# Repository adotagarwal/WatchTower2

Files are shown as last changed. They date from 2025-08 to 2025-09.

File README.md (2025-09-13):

# The Watch Tower WWVB transmitter - V2


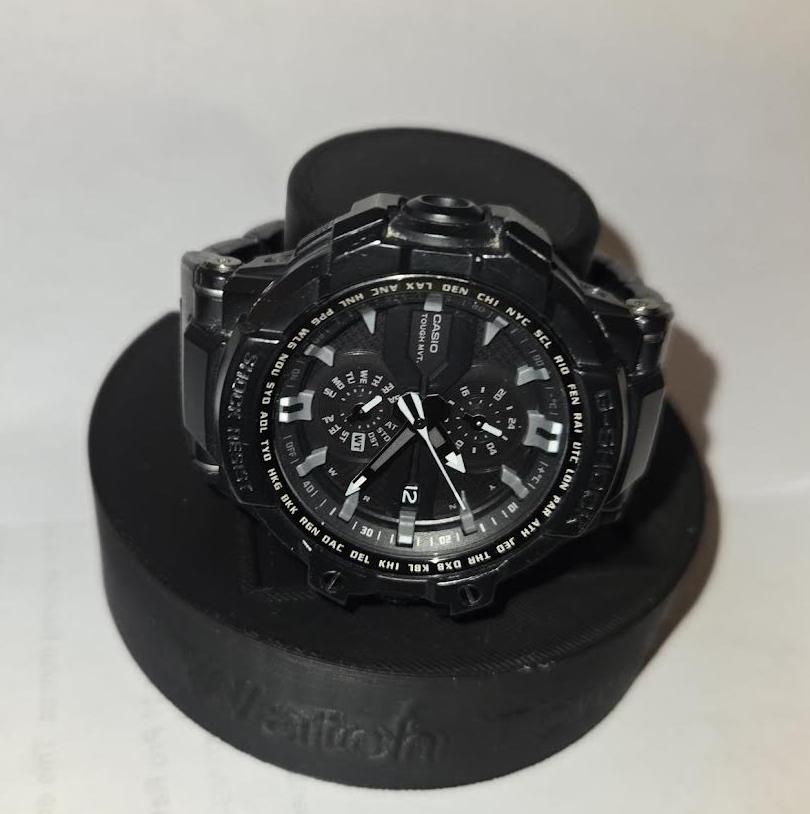
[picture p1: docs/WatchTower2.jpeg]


### This version has been updated to add a web gui for setting parameters (described in [424d3f8](https://github.com/adotagarwal/WatchTower2/commit/424d3f86f80151f93de71e6e73d6c25675c46d04)) and viewing log information, as well as supporting new protocols for time synchronization: WWVB, JJY (40&60), DCF77, MSF

This support was made possible by the work over at [time-signal](https://github.com/harlock974/time-signal) by Pierre Brial which I have adapted here.

## (NEW) UI
Settings tab preview:
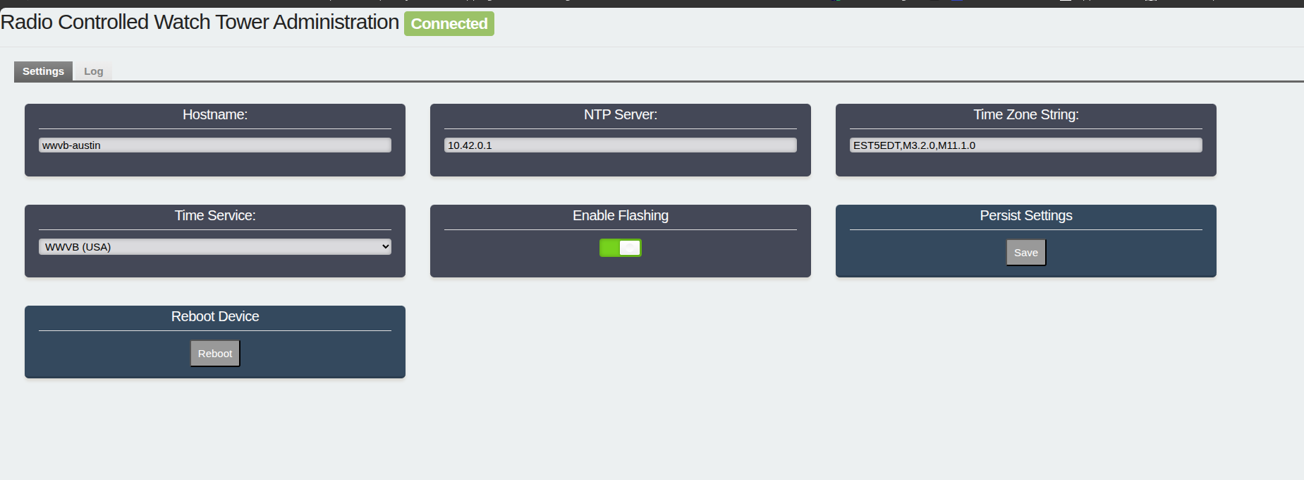
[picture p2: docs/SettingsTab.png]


Log tab preview:
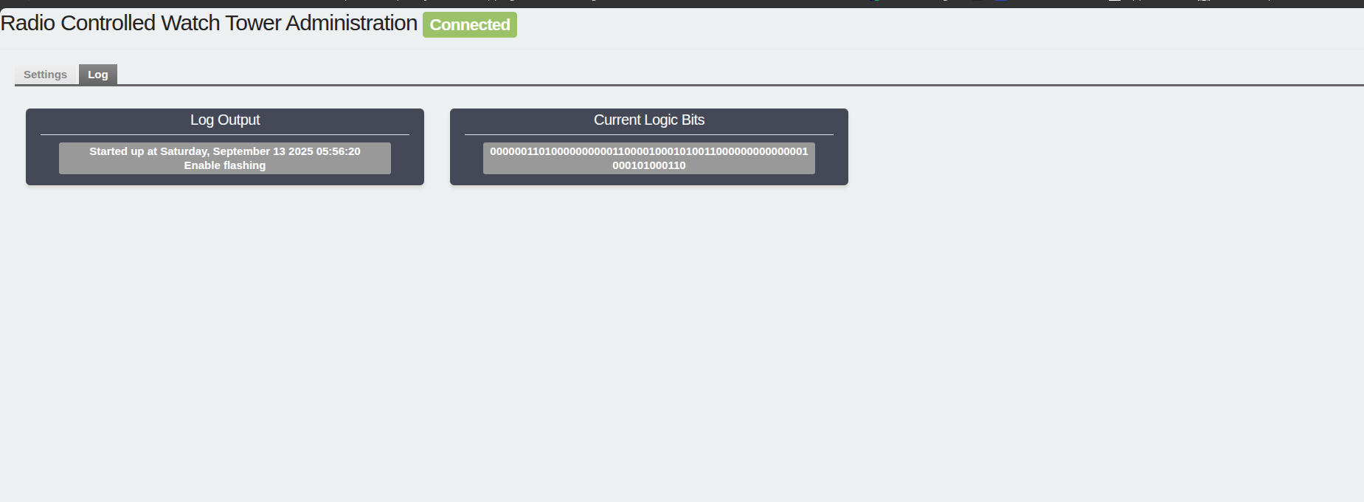
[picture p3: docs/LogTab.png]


Below is the original README

There are some beautiful radio-controlled watches available these days from Citizen, Seiko, Junghans, and even Casio. These timepieces don’t need fiddling every other month, which is great if you have more than one or two and can never remember what comes after “thirty days hath September…”

In the US, these watches work by receiving a 60-bit 1-Hz signal on a 60-kHz carrier wave broadcast from Fort Collins, Colorado called [WWVB](https://en.wikipedia.org/wiki/WWVB). The broadcast is quite strong and generally covers the entire continental US, but some areas of the country can have unreliable reception. I live in the SF Bay Area in an area with high RF noise and my reception can be spotty. My watches sync often enough that it’s not an issue 363 days out of the year, but sometimes they can miss DST shifts for a day or two. The east coast is known to be even more challenging. And people who live in other countries such as Australia have generally been out of luck.

Wouldn’t it be great if anyone anywhere in the world could set up a home transmitter to broadcast the time so their watches were always in sync?

WWVB has been around awhile and there have been various other projects ([1](https://www.instructables.com/WWVB-radio-time-signal-generator-for-ATTINY45-or-A/),[2](https://github.com/anishathalye/micro-wwvb)) that have demonstrated the feasibility of making your own WWVB transmitter. But these all had very limited range. I wanted to build something that could cover my whole watch stand and be based on a more familiar toolset for the typical hobbyist, namely USB-based 32-bit microcontroller development boards, WiFi, and Arduino. My goal was to make something approachable, reliable, and attractive enough it could sit with my watch collection.

## Is this legal?

The FCC requires a license to transmit, but has an [exemption](https://www.law.cornell.edu/cfr/text/47/15.209) for 60 kHz transmitters as long as the field strength is under 40 *μ*V/m at 300 meters. You will definitely not exceed this limit 💪🏼

## About WWVB

The classic WWVB transmits one bit of information per second (1Hz) and takes one minute (60 bits) to transmit a full time and date frame.

### An example

Here’s an example of one 60 second time encoding (graphic designed for "light mode"):

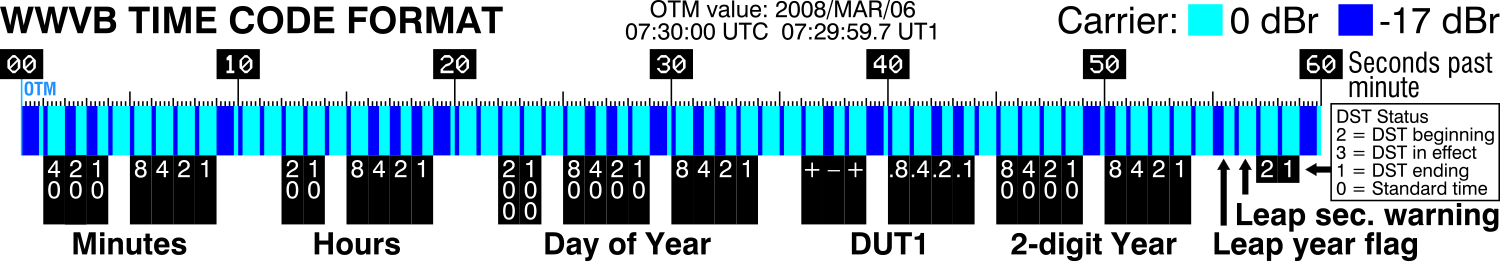
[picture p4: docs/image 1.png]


You can see that the minute of the time is encoded in the first 10 seconds of the window. The hour is in the next 10 seconds, the day is between seconds 22 and 33, etc.

If we wanted to indicate that the time was 30 minutes past the hour, for example, we would set bits 2 and 3 (20 and 10) to “high”. 

| **Bit** | **00** | **01** | **02** | **03** | **04** | **05** | **06** | **07** | **08** | **09** |
| --- | --- | --- | --- | --- | --- | --- | --- | --- | --- | --- |
| **Value** |  | 40 | 20 | 10 |  | 8 | 4 | 2 | 1 |  |
| *Example: 30* |  | *0* | *1* | *1* |  | *0* | *0* | *0* | *0* |  |

Similarly, the 7th hour of the day would be 0000111 for bits 12 thru 18.

### It’s a trit, not a bit.

How do we represent “high” and “low” for each 1s bit? You might think it would just be a high voltage for high and a low voltage for low, like you would use on a digital arduino pin, but that’s not how it’s done.

WWVB “bits” are actually not just 0 and 1. They’re actually "trits” because they can represent a 0, 1, or a “mark”, and this is one reason why we can’t just use a simple high/low to represent them. The mark is important to allow simple receivers to orient themselves within the signal window. Your watch knows that the last second in the window and the first in the next window are both “marks”, and so it knows to start a new window whenever it sees two marks in a row.

WWVB uses **Pulse Width Modulation** (PWM) to represent the three possible trit states. In a given 1 second bit, the width of the pulse determines whether the bit is a 0, 1, or mark.

- If power is reduced for one-fifth of a second (0.2 s), this is a data bit with value zero.
- If power is reduced for one-half of a second (0.5 s), this is a data bit with value one.
- If power is reduced for four-fifths of a second (0.8 s), this is a special non-data "mark", used for framing.

| **Low** | **Trit value** |
| --- | --- |
| 0.2s | 0 |
| 0.5s | 1 |
| 0.8s | mark |

Coming back to that original example but just focusing on the Minutes section, you can see the trits in the color encoding of the diagram. 

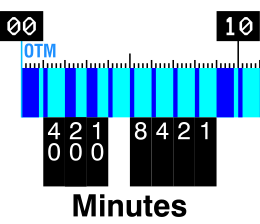
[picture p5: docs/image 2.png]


#07FEFF `Light blue` is high and #0001FC `Dark blue` is low. You can see second 00 is dark blue (low) for 0.8s, which means it’s a “mark”.  Second 01 is dark blue for 0.2s, so it’s a 0. Second 02 is dark blue for 0.5s so it’s a 1, and so on.

So now you know how to encode the time and date using WWVB!

### The carrier wave

There’s one more part of the signal that needs explanation. While we’re transmitting bits at a frequency of 1 bit per second (1 Hz), we’re actually doing it on top of a 60 kHz carrier wave by varying the amplitude of the carrier wave.

Like we said in the previous section, we represent a high/low/mark trit by the width of our pulse. High for 200ms is a zero, high for 500ms is a 1, high for 800ms is a mark. The way we’ll do that on our 60 kHz carrier wave is by using PWM again, but this time on the 60 kHz signal instead of on the 1 Hz signal. We’ll use a duty cycle of 50% to represent High, which means that half of our 60 kHz pulse is high and half is low. We’ll use a duty cycle of 0% to represent Low which effectively means the whole pulse is low.
 
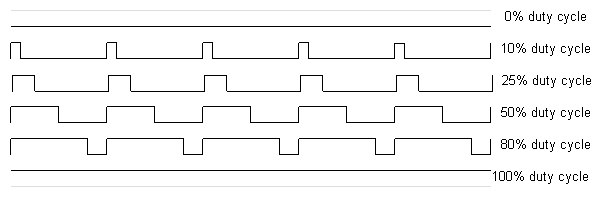
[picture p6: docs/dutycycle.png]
 

 So what you'll expect to see when you're transmitting a WWVB "mark" is a 1s pulse where half of the pulse is "high" using a 60 kHz signal at 50% duty, and the other half is "low" with a 0% duty (not to scale):

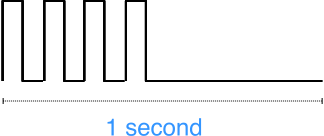
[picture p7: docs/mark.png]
mark
 

 Similarly, a 0 would be a 60 kHz 50% duty cycle for 0.2s, followed by a 0% duty cycle for 0.8s. And a 1 would be the reverse.

### The layers of WWVB

In summary, a WWVB date/time is encoded using a few different layers of encoding. At the top is what we think of as a date/time and at the bottom is the 60 kHz carrier wave.

|  |
| --- |
| A date/time is encoded as a… |
| 60-bit frame, using… |
| 1s PWM trits, on top of a… |
| 60 kHz 50% duty cycle carrier wave |
| 🐢🐢🐢 all the way down |

Now that you understand how it works, let’s build the transmitter!

## Components

- An ESP32-based development board such as the AdaFruit QT Py ESP32, AdaFruit Feather ESP32 v2, Arduino Nano ESP32, Seeed Xiao ESP32C3 or similar. I used the [QT Py ESP32](https://www.adafruit.com/product/5395).
- An H-bridge amplifier circuit. You can build your own, or I used the [Adafruit DRV8833 DC/Stepper Motor Driver Breakout Board](https://www.adafruit.com/product/3297). Boards using the TB6612 would probably also work, you just need something that can handle 5V or more, a few hundred milliamps and a switching frequency of 60khz or higher.
- One or two [60khz ferrite rod antennas](https://www.canaduino.ca/product/60khz-atomic-clock-receiver-v4-wwvb-msf-jjy60/). You can pull one from an existing quartz radio-controlled movement, or I bought mine from Canaduino. If you want better reliability at distance you may consider using a second antenna. Some users have had luck with a simple 20 inch length of straight copper wire, but I found the signal to be too weak to be reliable.
- Bread board and [jumper wires](https://www.amazon.com/dp/B08YRGVYPV).
- PCB Mount Screw Terminal Block connector to connect your antenna(s), something like [this](https://www.amazon.com/dp/B09F6TC7RP). Not strictly necessary but nice to have. Use a two pin terminal if you only plan to have one antenna, or a four pin if you want two antennas.

## Optional

None of the following is necessary, but some of it might be nice to have.

- **Oscilloscope**. It can be hard to know if your circuit is doing anything without an oscilloscope. There are some micro DSOs for around $100, and some android-based table DSOs for around $200, but I like the Rigol DHO800 series as an entry-level oscilloscope if your budget can stretch to around $400. A digital multimeter or an individual LED can also be helpful in a pinch.
- **10V power supply**. If you need more power you can use an external power supply. I found the signal to be strong enough without it and preferred the convenience of a single USB power supply. If you want to go up to 13V, switch to the [TB6612](https://www.adafruit.com/product/2448)
- **3D printer** if you would like to print the tower enclosure for your circuit.
- **Permaboard** or **Perma-proto**. After you’ve prototyped your circuit you’ll want to move it to something more permanent. [Perma-proto](https://www.adafruit.com/product/571) is convenient because it exactly matches your breadboard layout. Permaboard is more configurable but less convenient. Either one can be cut to size.
- **Soldering iron**. If you’re using permaboard, you’ll need a soldering iron. I love the [Pinecil v2](https://pine64.com/product/pinecil-smart-mini-portable-soldering-iron/), it’s USB-powered, auto-sleep, nearly instant-on, open-source and temperature controlled.
- **GPS module**. The nice thing about using module development boards like the Feather, Grove, Arduino, etc. is their support for additional modules. The [AdaFruit Ultimate GPS FeatherWing](https://www.adafruit.com/product/3133) pairs well with their Feather boards and includes an accurate RTC. If you go GPS, you don’t necessarily need a microcontroller with WiFi.
- **LCD display**. This can be a nice touch and can make it easier to tell if your tower is working or not. I like the [Adafruit ESP32 TFT Feather](https://www.adafruit.com/product/5483) or similar. I made an earlier prototype with a screen that displayed the current time, but didn’t like the way the screen lit up my bedroom at night. You can also connect many external displays using the simple I2C connector on many dev boards.

## Instructions

### Simulator

Before you get started, you might be interested to see a simplified version of the software in action on the Wokwi Arduino online simulator.

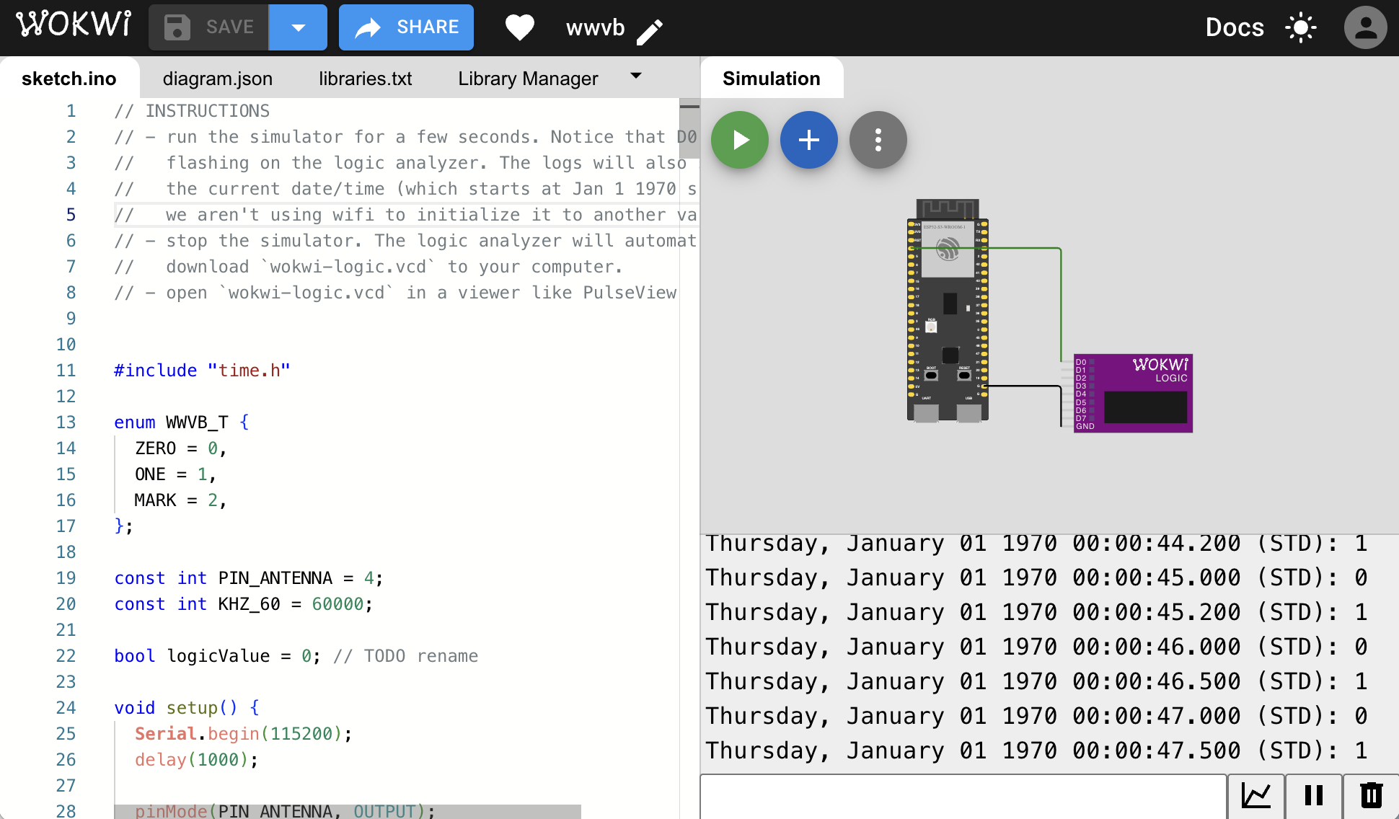
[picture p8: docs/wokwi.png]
The Watch Tower on Wokwi (https://wokwi.com/projects/431240334467357697)

https://wokwi.com/projects/431240334467357697

This simulator connects a virtual Arduino to a virtual logic analyser on PIN 4, and lets you download the output
of PIN 4 for offline viewing on your computer.

To use it:

- Run the simulator for a few seconds. Notice that D0 is
  flashing on the logic analyzer. The logs will also show
  the current date/time (which starts at Jan 1 1970 since
  we aren't using wifi to initialize it to another value)
- Stop the simulator. The logic analyzer will automatically
  download `wokwi-logic.vcd` to your computer.
- Open `wokwi-logic.vcd` in a viewer like [PulseView](https://sigrok.org/wiki/PulseView)

### Software

https://github.com/emmby/WatchTower

Upload the Arduino sketch to your Arduino using the Arduino IDE.

The LED will light up yellow/orange while connecting to WiFi. If you haven’t yet set your SSID, connect your phone to SSID: WWVB and follow the instructions to enter your wifi password.

Once the network is connected and the time has sync’d, the light will turn green briefly and then turn off.

**Setup()**

The Arduino setup() method does a few things.

Initialize the components we’ll be using, particularly the serial port, LEDs, WiFi, output pins, timezone, and network time sync (NTP). The network time sync will happen automatically in the background every hour. This is important because the realtime clock (RTC) on most microcontrollers are notoriously subject to drift and are rarely accurate for more than a few hours.

Start the 60 kHz carrier wave at a 50% duty cycle.

**Loop()**

Arduino then moves to the loop(), which continuously performs the following operations:

- Get the current time in UTC
- Convert it to your local timezone to determine DST
- Compute whether the 60 kHz carrier wave should be set to 50% (logical high) or 0% (logical low) for that specific moment in time. Time is always UTC, except for the DST bit which is relative to your local timezone.
- Set the PIN_ANTENNA to high or low based on that value.
- [Optional] you can flash the led for high/low PWM. This is nice for making sure things are working, but it’s grounds for divorce in the bedroom.

Do some other nice-to-haves like logging, setting LEDs and/or rebooting when there are issues.

### Verify the microcontroller alone

If you installed and ran your software and you set up the wifi connection, your board should now be outputting a signal on your output pin.

If you have an LED, you can connect the long end (anode) to your output pin and the other end to ground. If everything is working it should flash on/off about once a second.

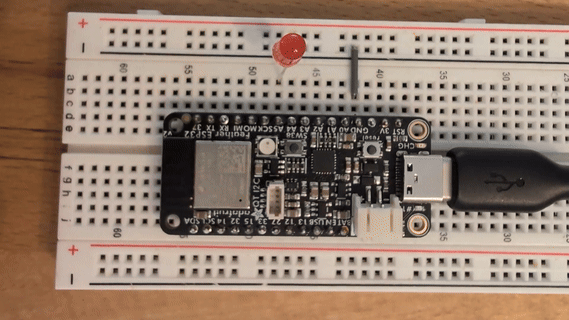
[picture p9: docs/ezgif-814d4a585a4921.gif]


If you have a digital oscilloscope, you should be able to see a 3V square wave with a periodicity of 16us (1 / 60,000) something like the following:

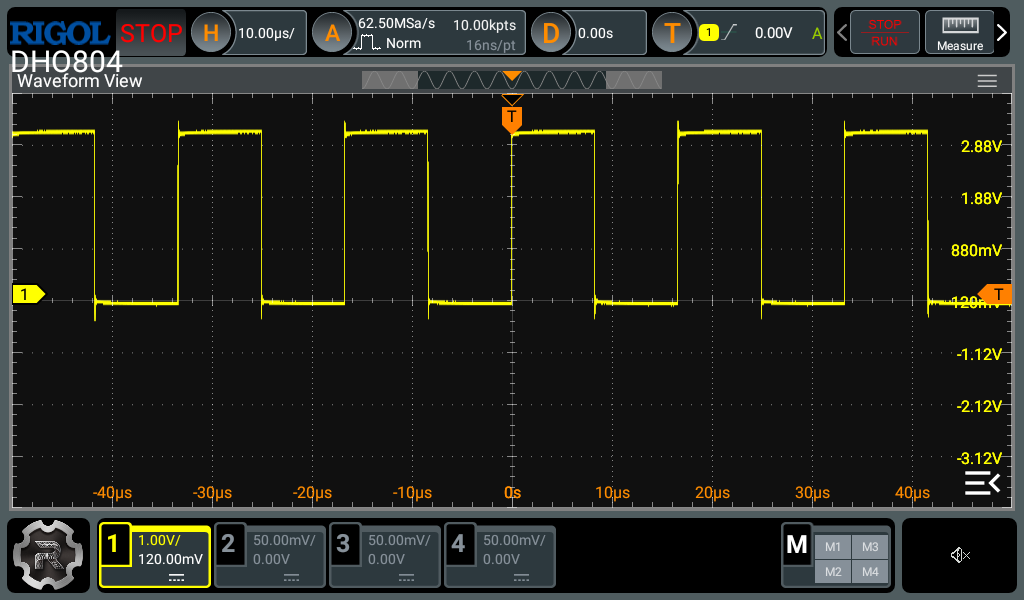
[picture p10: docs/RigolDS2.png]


That’s the 50% duty cycle PWM carrier wave initialized during setup().

If you zoom out to say 1 second per grid square resolution, you’ll be able to see the WWVB signal clearly:

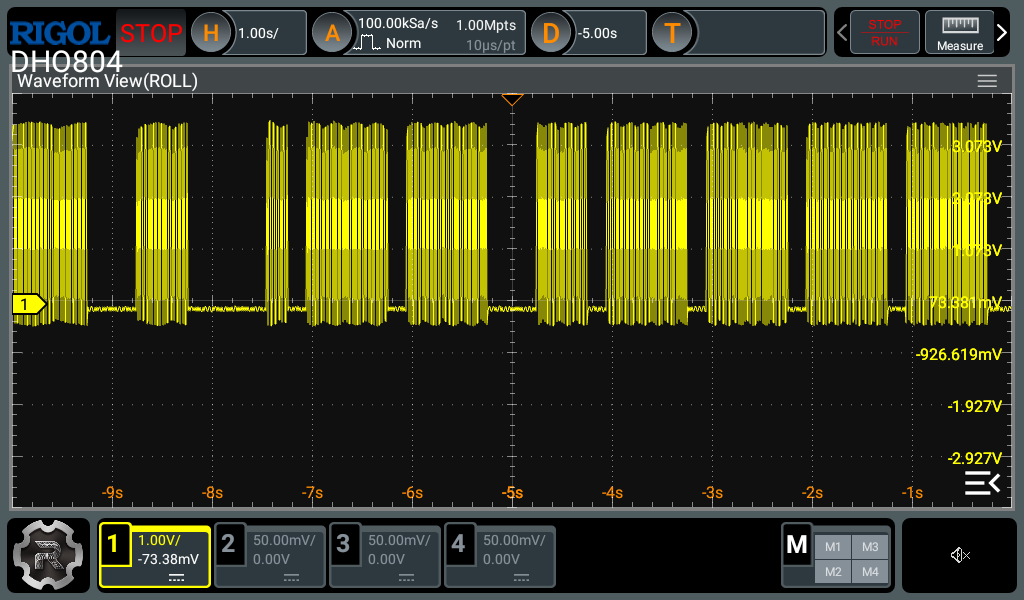
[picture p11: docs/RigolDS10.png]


In the 10 seconds shown here, I see a 1, mark, 0, 1, 1, mark, 1, 1, 1, and 1.

Now if you modify the software to hardcode the date to Mar 6, 2008 7:30:00 am and zoom out to see a full 60 seconds, your signal should exactly match the signal in the example we started with:

```c
  buf_now_utc.tm_year = buf_now_local.tm_year = 108; // 2008 = 1900 + 108
  buf_now_utc.tm_yday = buf_now_local.tm_yday = 65;
  buf_now_utc.tm_mon = buf_now_local.tm_mon = 2;
  buf_now_utc.tm_mday = buf_now_local.tm_mday = 6;
  buf_now_utc.tm_hour = buf_now_local.tm_hour = 7;
  buf_now_utc.tm_min = buf_now_local.tm_min = 30;
```

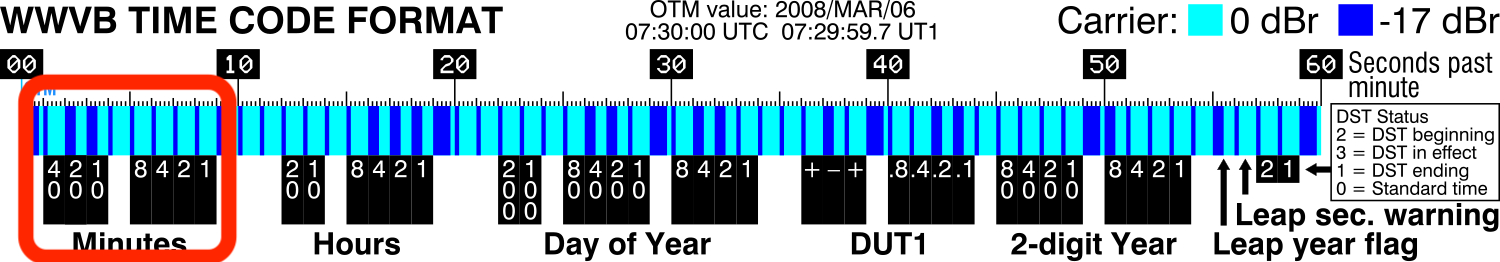
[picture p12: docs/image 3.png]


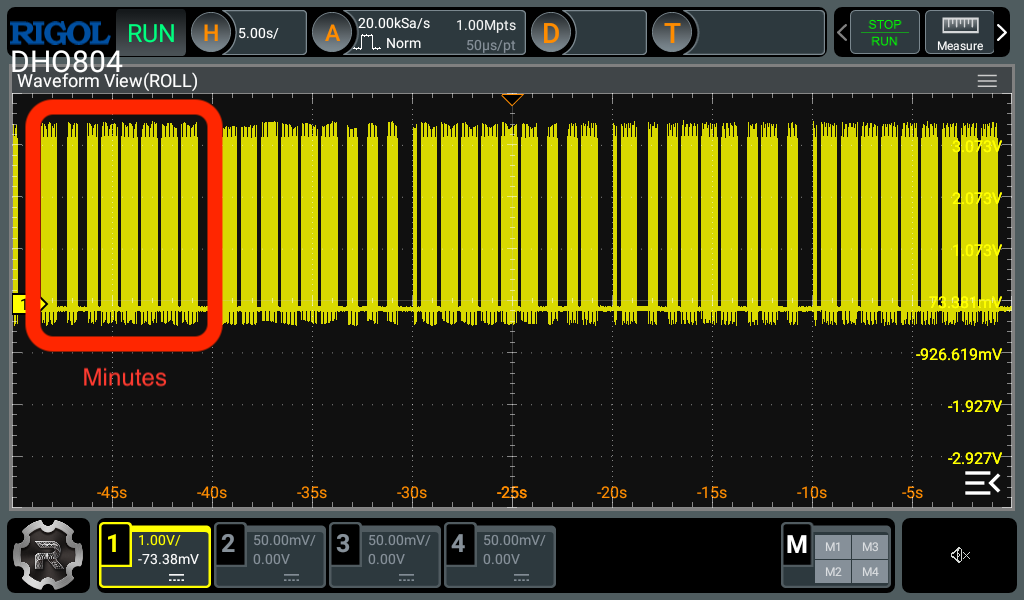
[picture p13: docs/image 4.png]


Looks great! Everything is working as expected.

### Electronics assembly

Now that you’ve verified the microcontroller is working, it’s time to put all the components together.

The electronics consist of three basic components: the microcontroller board, the amplifier breakout board, and the antenna(s).

The connections are quite simple, you can do them on a breadboard or a proto board. I recommend starting with a breadboard, which will look identical to this perma-proto board but without the solder:

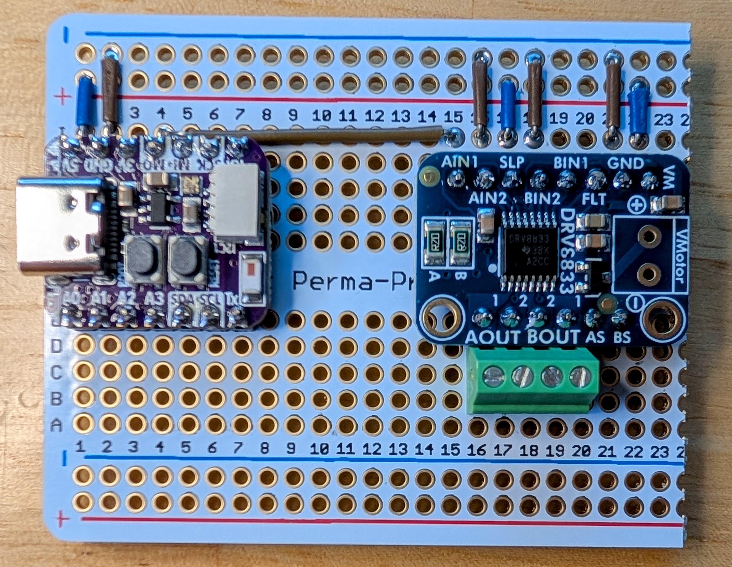
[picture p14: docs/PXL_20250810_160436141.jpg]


**Microcontroller board** (Adafruit ESP32 QT Py in this photo)

- Connect the 5V pin to the power plane (photo: J1).
- Connect the ground pin to the ground plane (photo: J2).
- Connect your signal pin [M0] to the input pin of your amplifier [AIN1] (photo: J4>J15).

**DRV8833 Amplifier breakout**

I decided to leave a gap between my microcontroller board and my amplifier board. This will support an optional second antenna mounted vertically, and it also makes it easier to access the STEMMA QT I2c connector on the QT Py.

- Connect the second input pin [AIN2] of your amplifier to ground (photo: J16).
- The Adafruit DRV8833 motor driver board has a sleep pin that needs to be pulled high to enable the breakout, so connect that to power 5v or 3v power, whatever is convenient. We used 5V here. (photo: J17)
- Connect ground to the ground plane. (photo: J21)
- [Optional] Connect the “motor” voltage [VM] to your 5V plane (photo: J22). This is needed if you are powering your amplifier via USB like I have here, but it should not be done if you are planning to use an external power supply on VMotor.
The antenna and amplifier circuit can contribute some noise to your 5V line. If you’re worried about it you might use an external power supply instead, but I found for these settings that the noise was negligible (although see Alternatives Considered for some lessons learned).
- Optional: connect BIN2 to ground (photo: J18). This is only needed if you want to use a second antenna.
- Optional: connect BIN1 to AIN1 (**not in photo**: I15>I19). For a second antenna.

**Antenna(s)**

- You can plug your antennas directly into your breadboard, or use a 0.1" Pitch PCB Mount Screw Terminal Block Connector connected to [AOUT1], [AOUT2], [BOUT2], and [BOUT1] (photo: C16, C17, C18, C19). If you are only using one antenna, you only need [AOUT1] and [AOUT2].

  The orientation of the antenna has a profound effect on the strength of the signal. I recommend using a second antenna at a 90 degree orientation to the first. You won't get a more powerful signal, but by having a second signal at a 90 degree orientiation you significanly increase the chance that your watches will be able to pick up a signal (see the section on antenna orientation below). The amplifier can easily handle two antennas.

  With one antenna, I was getting around 12 inches of range with the way my watches were oriented. With the second antenna, that jumped up to more than 6 feet!

  The STL tower has a hole in the center to allow space for a 60mm ferrite rod antenna mounted vertically in the gap between the microcontroller and amplifier PCBs.

### Signal Verification

You should be able to do the same LED trick as last time, only this time with the long anode on AOUT1 and the short cathode on AOUT2.

Or with your oscilloscope, you can look at the output of your microcontroller and compare it to the output of your amplifier:

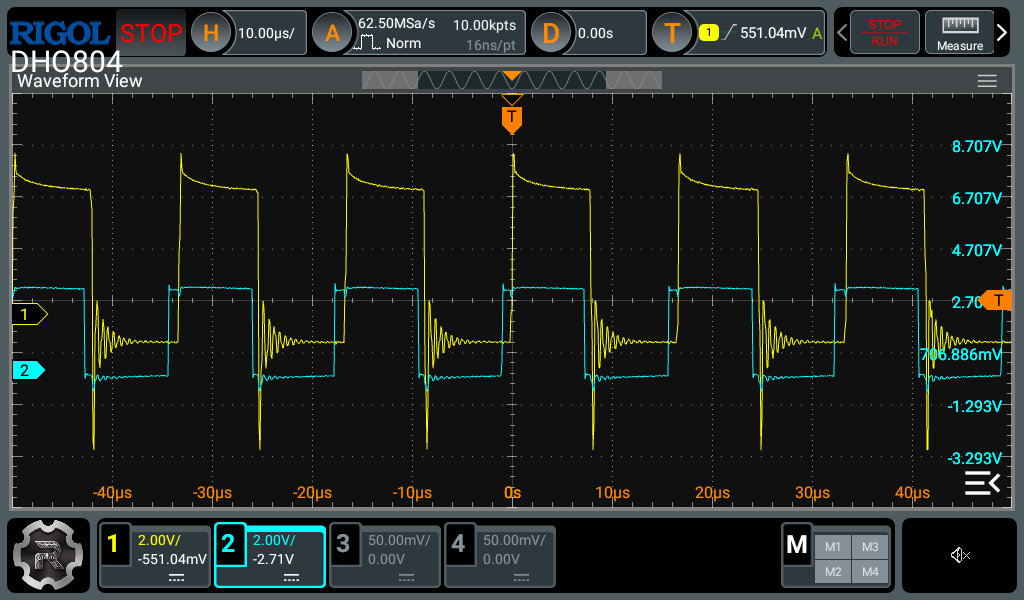
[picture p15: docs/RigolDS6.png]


Here the 3V signal on the microcontroller is blue, and you can see that the amplifier is outputting a similar wave but at 5V. If your wave doesn’t look quite like this, check that your antenna is plugged in. The antenna has an impedance that will cause the ringing that you see in the waveform, that’s expected and okay.

The final test is to verify it works with a real watch!



### Assembling the enclosure

The enclosure is designed for a 51mm x 63mm perma-proto, which is the size of a half size perma-proto with the excess trimmed. You can trim a proto board by scoring along a straightedge with a utility knife and then bending the board at the score, either by pressing it down on a hard surface at an angle or using a vise grip. Or feel free to modify the Autodesk Fusion file to the size of your own board.

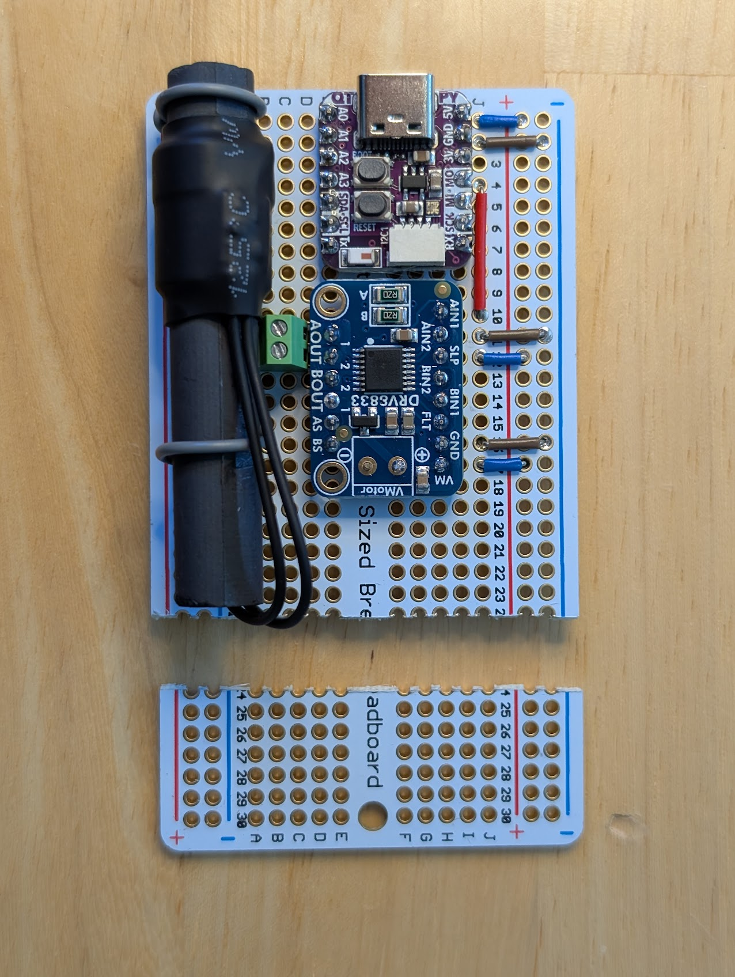
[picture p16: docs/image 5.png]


Here I also made a quick and dirty “mount” for the antenna by twisting a couple of loops of wire and soldering them to the perma proto. Hot glue also works great.

Print the enclosure using a 3D printer. I used standard PLA, standard 0.4mm nozzle, and pretty much default slicer settings with no supports.

* STL: [The Watch Tower.stl](enclosure/The%20Watch%20Tower%20v18.stl)
* Autodesk Fusion: [The Watch Tower.f3d](enclosure/The%20Watch%20Tower%20v18.f3d)

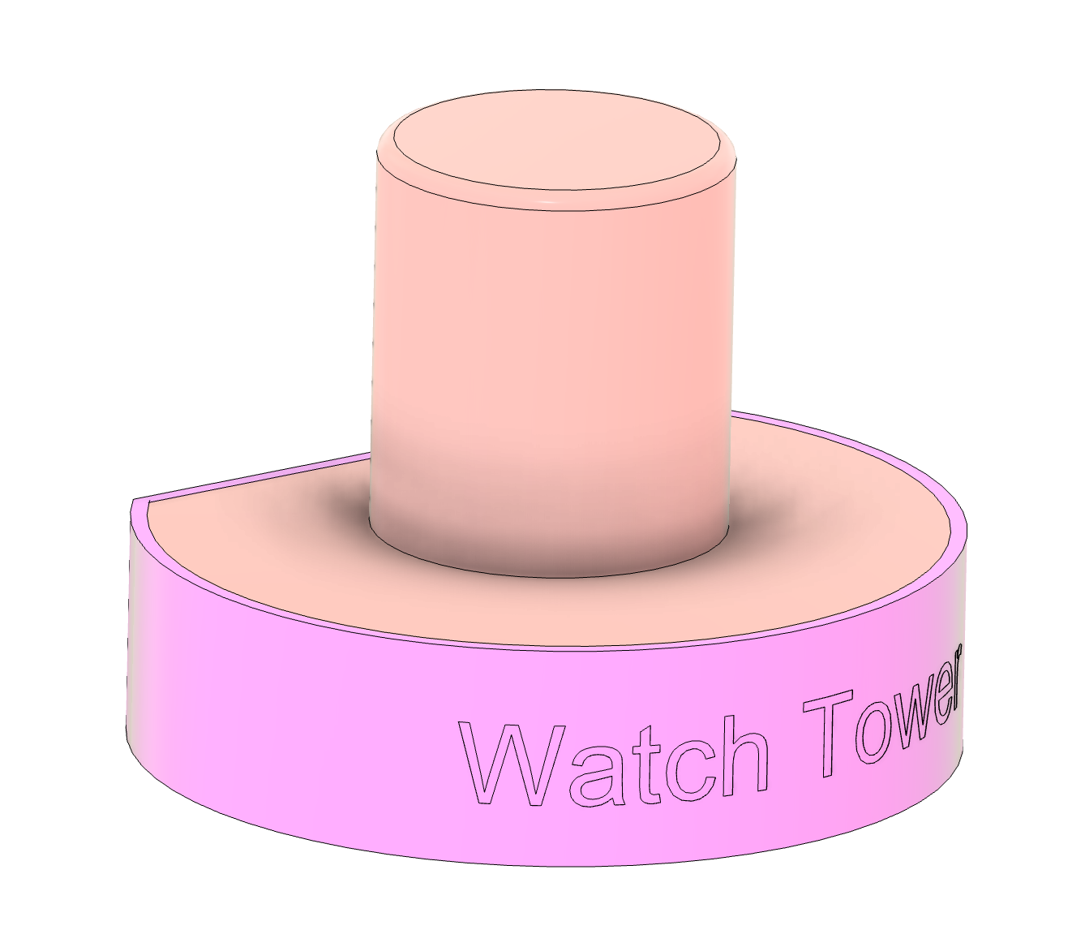
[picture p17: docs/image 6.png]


Insert the circuit board into the base. Orient the second antenna between the two PCBs and fit it into the hole in the tower. Then press the lid for a snap fit.

## Enjoy!

Plug into USB and you’re done! Your watches should now sync automatically every night.

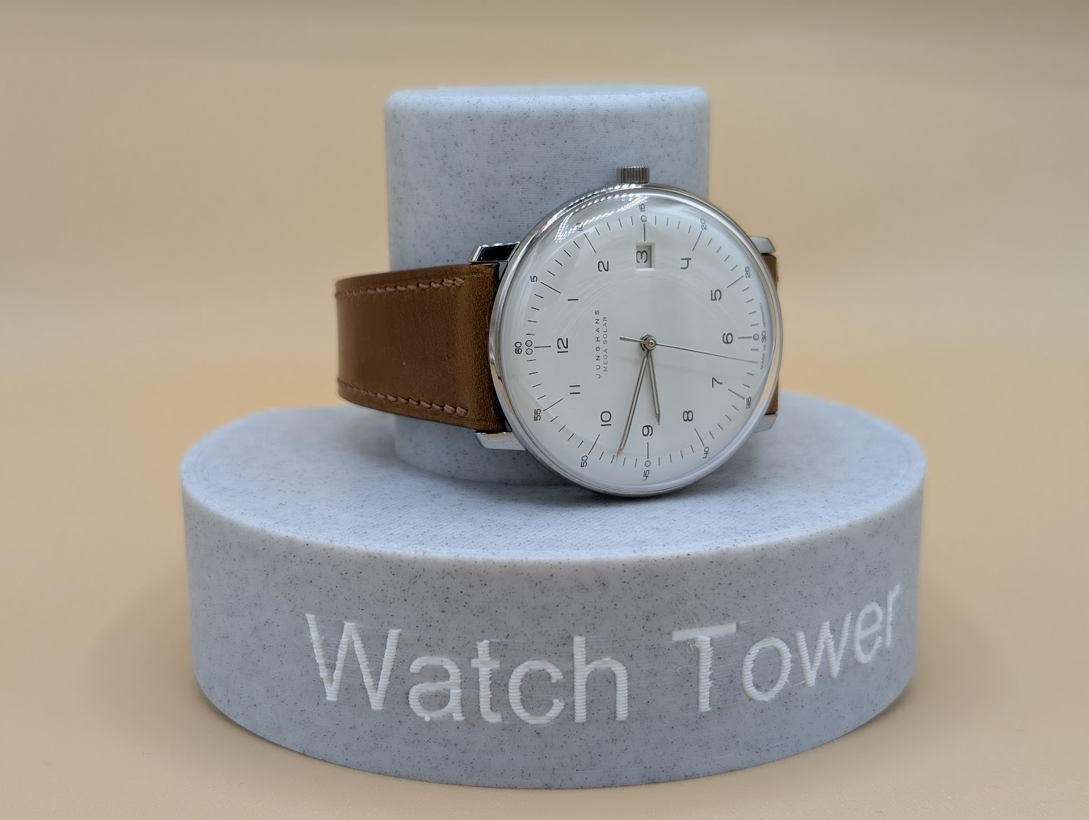
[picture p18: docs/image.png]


## Signal strength

### How does distance affect signal strength?

You probably expect the signal to decrease as you get further away from the tower, but you might be surprised by how quickly the signal disappears.

The "inverse square law" tells us that RF signal strength decreases with the square of the distance. We can measure our signal strength using our oscilloscope, another antenna, and a ruler.

signal strength at 1 inch setup

At one inch, our signal strength looks pretty solid! You can see that our 5V antenna square wave (yellow) is inducing a 16V sinusoidal wave in our receiving antenna. It's a little counter-intuitive that the receiving amplitude would be larger than the sending amplitude, but RF physics is beyond the scope of this README. Which is another way of saying 🤷.

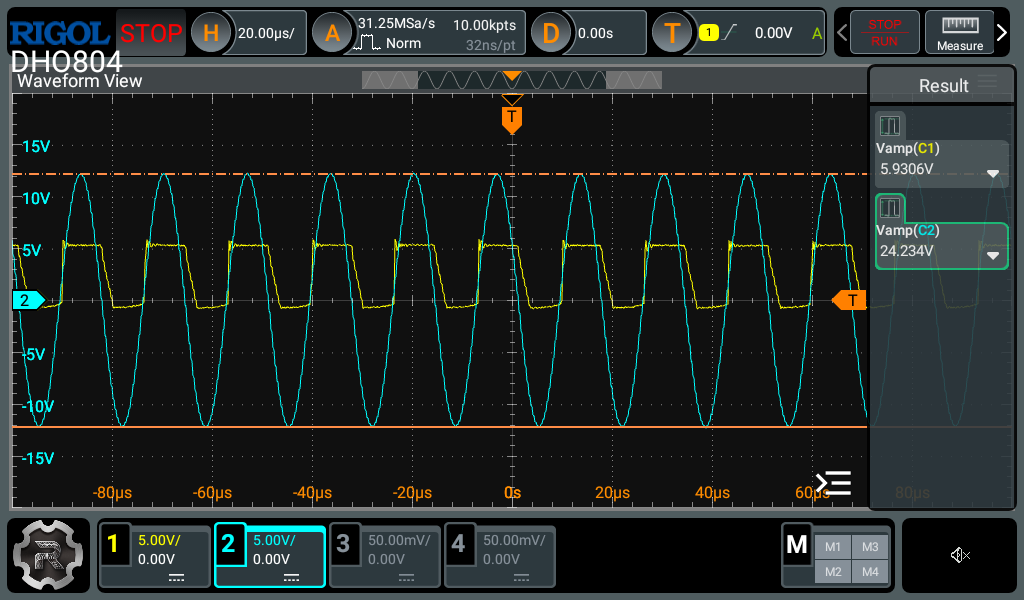
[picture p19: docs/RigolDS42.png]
signal strength at 1 inch


Here are my readings as I move the receiver antenna further out. As expected, the amplitude decreases by roughly 4X as the distance doubles. 

| Distance | Amplitude |
|----|---|
| 1" | 24.2V |
| 2" | 6.7V |
| 4" | 1.2V |
| 8" | 301mV |
| 16" | 93mV |
| 32" | 28mV |

When you zoom out, the one second pulses are still clearly distinguishable to the human eye, but it gets harder and harder as you get further away.

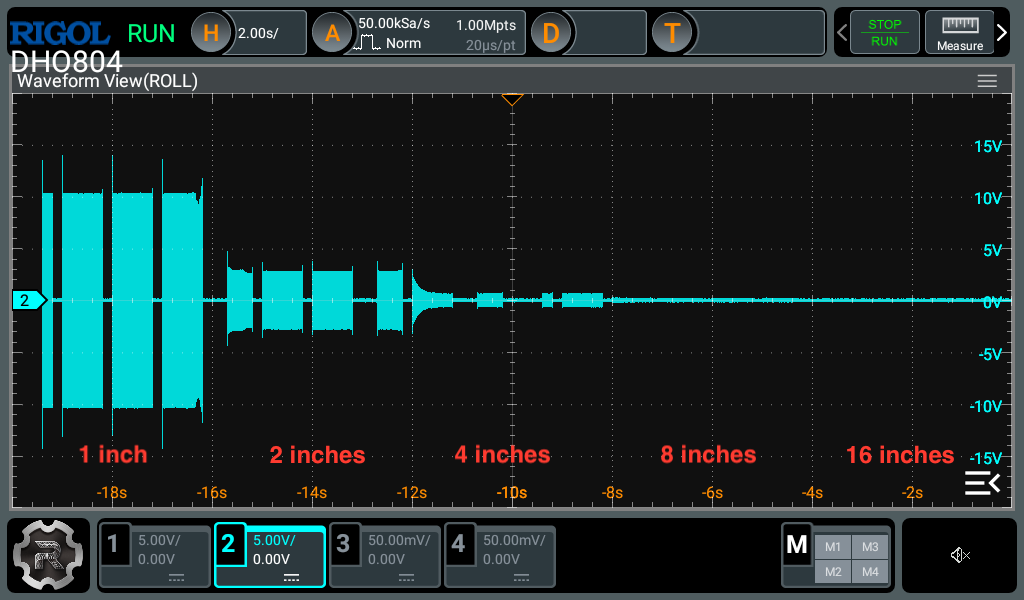
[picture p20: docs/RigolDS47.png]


This is all fine and good, but seeing a wave on an oscilloscope doesn't necessarily mean the watch can pick it up. We'll get into that shortly.

### How does orientation affect signal strength?

Quite a lot!

Turning the receiver antenna 90 degrees drops the signal by 75%!

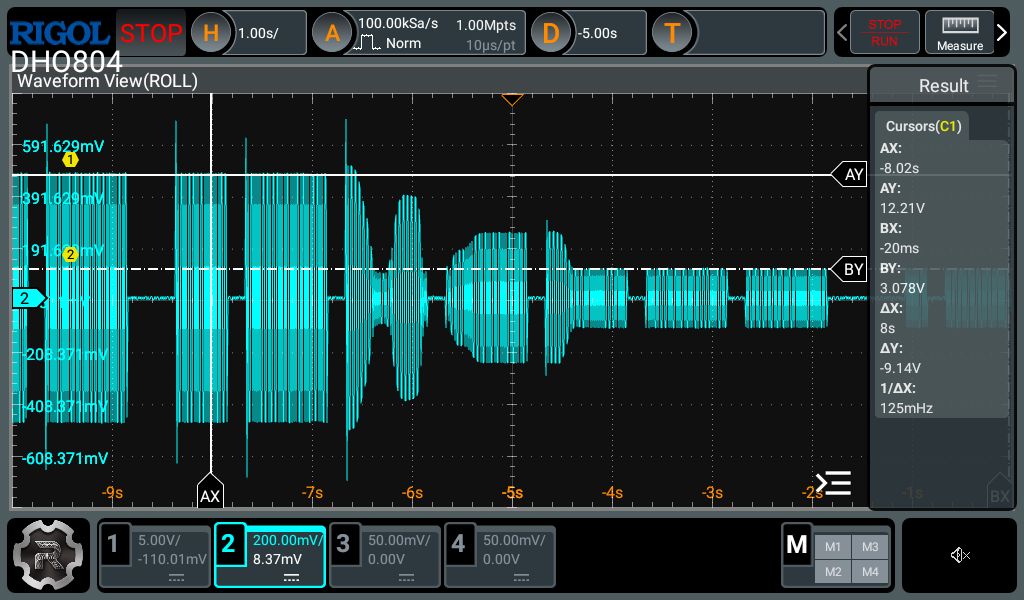
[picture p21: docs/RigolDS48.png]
rotation


Most watches receive their strongest signal through the watch face. For the best reception you should point your watch toward the tower (or toward Colorado). This may make more of a difference than a few inches of distance.

This doesn't matter for watches on the stand where the signal is strong, but it can make a difference for watches that are further away.

This is why I recommend two antennas at right angles from each other.

### Does the enclosure affect signal strength?

Plastic enclosures have a negligible effect on signal strength. The Watch Tower enclosure printed using generic PLA has maybe 5% or less of an impact on signal strength. Again, a few degrees of orientation will have a larger effect than an enclosure.

|||
|-|-|
|No enclosure | 1.02V |
|Base | 952mV |
|Fully enclosed | 987mV |

### How far away can my watch pick up the signal?

Watches vary in terms of their antenna design, their enclosures, antenna orientation, signal-to-noise filtering, etc.

I tested with a Junghans Max Bill Mega Solar 59/2021.02 (Seiko movement) and a Casio Lineage LIW-M700D (Casio movement). In practice, the orientation of your watch will probably have orders of magnitude more influence on your reception than the model of your watch.

Using the SINGLE antenna, I made five attempts with each watch at a distance of 9" with the antenna and the watch both flat on the surface. To minimize interference from Fort Collins, I placed everything inside a poor man's faraday cage (a stainless steel stock pot with a tight lid, which Gemini tells me is reasonably effective at blocking 60 kHz signals). For each attempt, I gave the watch 5 minutes to try to set the time before I lifted the lid. 

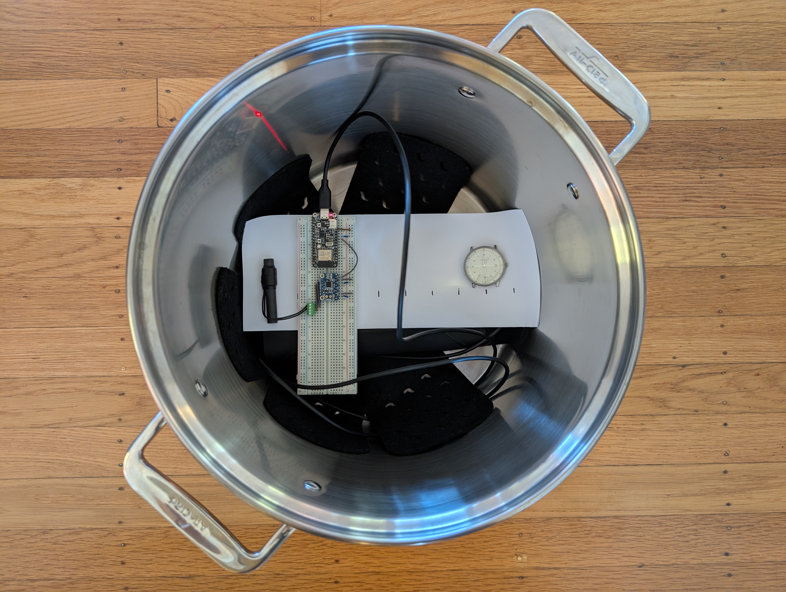
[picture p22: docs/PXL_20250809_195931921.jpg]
clock in a pot


| Model ||||||
|---|-----|-|-|-|-|
| Casio | Yes | No | Yes | Yes | Yes |
| Junghans| Yes | Yes | Yes | Yes | Yes |

Outcome: ~90% success at 9" (single antenna)

In practice, I've found that watches on the Watch Tower will reliably sync every time, and most watches on my nearby watch stand will also sync most of the time using a single antenna. Adding the second antenna increases reliability to basically 100%.

## Alternatives considered

- I wanted to avoid using a separate amplifier breakout board so I tried the Adafruit RP2040 scorpio. It can do 60khz PWM at 5V natively, but it was only able to drive 12mA per channel which wasn’t enough to saturate my ferrite antenna so the square wave collapsed.
- I looked at the **Adafruit 8-Channel PWM or Servo FeatherWing** because I wanted to take advantage of module stacking, but it can only do 10mA per channel and 1.6khz.
- I looked at Trinket and Itsybitsy ATmega based boards, but they can’t drive much current and they’re not modular with anything and they have no wifi so there’s little advantage over the QT Py.
- I considered driving the DRV8833 with an external power supply. This would have given me higher voltage and likely a stronger signal. But I wanted the convenience of a single usb power supply, and the signal strength was sufficient for my needs.
- ⚠️ **WARNING**: I tried the linking both the A and B H-bridges of the  DRV8833 in parallel, and I also upped the duty cycle to 80%. Totally blew out my microcontroller, presumably with a flyback voltage due to the high inductance antenna. I’m not sure if it was the parallel or the 80% or the combination of the two, it would be worth experimenting further but I haven’t yet.

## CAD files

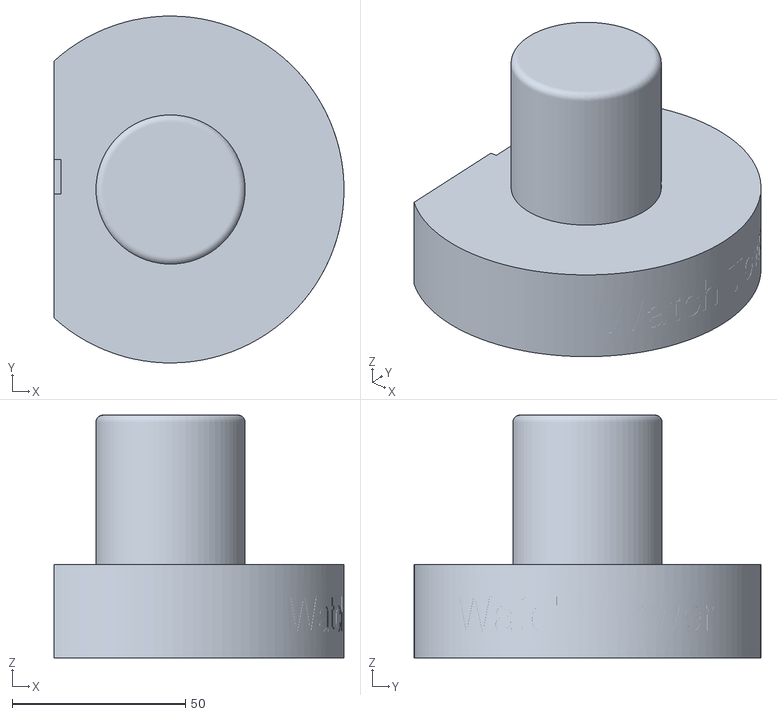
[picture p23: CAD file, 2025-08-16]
enclosure/original/The Watch Tower v18.stl
83.6 x 100.0 x 70.0

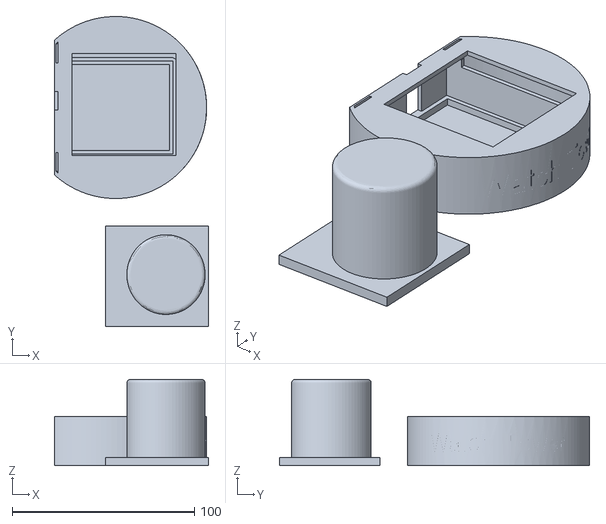
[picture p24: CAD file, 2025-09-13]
enclosure/WWVB Radio Watch Tower.stl
84.6 x 170.3 x 47.4

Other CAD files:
enclosure/original/The Watch Tower v18.f3d

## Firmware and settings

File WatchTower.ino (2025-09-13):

// INSTRUCTIONS
// - set the PIN_ANTENNA to desired output pin
// - download and run the code on your device
// - connect your phone to "WWVB" to set the wifi config for the device

// Designed for the following, but should be easily
// transferable to other components:
// - ESP32: https://www.adafruit.com/product/5395
// - DRV8833 breakout: https://www.adafruit.com/product/3297

#include <WiFiManager.h>
#include <Preferences.h>
#include <ESPUI.h>
#include "time.h"
#include "esp_sntp.h"
#include "time-services.h"
#include "wwvb-impl.h"

// Set these values to the pin numbers corresponding to those your antenna and onboard led are connected
const int PIN_ANTENNA = 23;
const int PIN_LED = 2;

//STATE VARIABLES
WiFiManager wifiManager;
Preferences thePreferences;
bool logicValue = 0; // TODO rename
uint64_t logicBits = 0;
struct timeval lastSync;
uint16_t liveLogHandle;
uint16_t liveLogicBitsHandle;
String logBuffer = "";

// PREFERENCE VARIABLES
bool enableFlashing = false;
enum time_service theService = WWVB;
String theNtpServer;
String theTimezone;
String theHostname;

// TIMEZONES: https://gist.github.com/alwynallan/24d96091655391107939

// A tricky way to force arduino to reboot
// by accessing a protected memory address
void(* forceReboot) (void) = 0;

// A callback that tracks when we last sync'ed the
// time with the ntp server
void time_sync_notification_cb(struct timeval *tv) {
    lastSync = *tv;
}

// A callback that is called when the device
// starts up an access point for wifi configuration.
// This is called when the device cannot connect to wifi.
void accesspointCallback(WiFiManager*) {
    Serial.println("Connect to WWVB with another device to set wifi configuration.");
}

void setup() {
  Serial.begin(115200);
  delay(1000);
  Serial.println("Starting...");
  
  pinMode(PIN_ANTENNA, OUTPUT);
  pinMode(PIN_LED, OUTPUT);

  // hack for this on esp32 qt py?
  // E (14621) rmt: rmt_new_tx_channel(269): not able to power down in light sleep
  digitalWrite(PIN_ANTENNA, 0);
  //digitalWrite(PIN_LED, 0);

  readPreferences();

  WiFi.setScanMethod(WIFI_ALL_CHANNEL_SCAN);

  Serial.println("Connecting to Wi-Fi...");

  // Connect to WiFi using // https://github.com/tzapu/WiFiManager 
  // If no wifi, start up an SSID called "WWVB" so
  // the user can configure wifi using their phone.
  wifiManager.setAPCallback(accesspointCallback);
  wifiManager.autoConnect(theHostname.c_str());

  Serial.println("Syncing NTP time...");

  // Connect to network time server
  // By default, it will resync every hour
  sntp_set_time_sync_notification_cb(time_sync_notification_cb);
  configTime(0, 0, theNtpServer.c_str());
  struct tm timeinfo;
  if(!getLocalTime(&timeinfo)){
    Serial.println("Failed to obtain time");
    flashFailure();
    delay(3000);
    forceReboot();
  }
  Serial.println("Got the time from NTP");
  flashSuccess();

  // Now set the timezone.
  // We broadcast in UTC, but we need the timezone for the is_dst bit
  updateTimezone();

  // Start the 60khz carrier signal using 8-bit (0-255) resolution
  int myFrequency = getFrequencyForService(theService);

  ledcAttach(PIN_ANTENNA, myFrequency, 8);
  
  createUi();

  char timeStringBuff[100]; // Buffer to hold the formatted time string
  strftime(timeStringBuff, sizeof(timeStringBuff), "%A, %B %d %Y %H:%M:%S", &timeinfo);
  appendToLogFormat("Started up at %s", timeStringBuff);

  // green means go
  flashSuccess();
}

void loop() {
  struct timeval now; // current time in seconds / millis
  time_t nowRounded; // current time in hour, minute (no seconds)
  struct tm buf_now_utc; // current time in UTC
  struct tm buf_now_local; // current time in localtime
  struct tm buf_today_start, buf_tomorrow_start; // start of today and tomrrow in localtime

  gettimeofday(&now,NULL);
  nowRounded = now.tv_sec - now.tv_sec % 60;
  localtime_r(&now.tv_sec, &buf_now_local);

  // DEBUGGING Optionally muck with buf_now_local
  // to make it easier to see if your watch has been set
  if (false) {
    // I like to adjust the time to something I can tell was 
    // set by the Watch Tower and not by Fort Collins.

    // If you set the time/date ahead, be aware that the
    // code will reboot if you set the time more than 4 hours
    // ahead of lastSync.

    // If you hardcode to a fixed date, be aware that some watches
    // may not sync the date every night (presumably to save battery
    // or speed up the sync process), so the date may not always be
    // what you expect even though the watch says it sync'd.

    // Subtract two weeks from today's date. mktime will do the right thing.
    buf_now_local.tm_mday -= 14;
    
    // write your changes back to now and buf_now_local
    now.tv_sec = mktime(&buf_now_local);
    localtime_r(&now.tv_sec, &buf_now_local);
  }

  gmtime_r(&now.tv_sec, &buf_now_utc); 

  // compute start of today for dst
  struct timeval today_start = now;
  today_start.tv_usec = 0;
  today_start.tv_sec = (today_start.tv_sec / 86400) * 86400; // This is not exact but close enough
  localtime_r(&today_start.tv_sec, &buf_today_start);

  // compute start of tomorrow for dst
  struct timeval tomorrow_start = now;
  tomorrow_start.tv_usec = 0;
  tomorrow_start.tv_sec = ((tomorrow_start.tv_sec / 86400) + 1) * 86400; // again, close enough
  localtime_r(&tomorrow_start.tv_sec, &buf_tomorrow_start);

  const bool prevLogicValue = logicValue;
  const uint64_t prevLogicBits = logicBits;

  if (theService == LEGACY) {
    logicValue = wwvbLogicSignal(
        buf_now_utc.tm_hour,
        buf_now_utc.tm_min,
        buf_now_utc.tm_sec, 
        now.tv_usec/1000,
        buf_now_utc.tm_yday+1,
        buf_now_utc.tm_year+1900,
        buf_today_start.tm_isdst,
        buf_tomorrow_start.tm_isdst
        );
  } else {
    logicBits = prepareMinute(theService, nowRounded);
    int myModulation = getModulationForSecond(theService, logicBits, buf_now_utc.tm_sec);
    logicValue =  getLogicForMillisecond(theService, myModulation, now.tv_usec/1000);
  }

  if( logicValue != prevLogicValue ) {
    ledcWrite(PIN_ANTENNA, dutyCycle(logicValue));  // Update the duty cycle of the PWM

    // light up the pixel if desired
    if( logicValue == 1 && enableFlashing) {
      digitalWrite(PIN_LED, HIGH);
    } else {
      digitalWrite(PIN_LED, LOW);
    }

    // do any logging after we set the bit to not slow anything down,
    // serial port I/O is slow!
    char timeStringBuff[100]; // Buffer to hold the formatted time string
    strftime(timeStringBuff, sizeof(timeStringBuff), "%A, %B %d %Y %H:%M:%S", &buf_now_local);

    char lastSyncStringBuff[100]; // Buffer to hold the formatted time string
    struct tm buf_lastSync;
    localtime_r(&lastSync.tv_sec, &buf_lastSync);
    strftime(lastSyncStringBuff, sizeof(lastSyncStringBuff), "%b %d %Y %H:%M", &buf_lastSync);
    Serial.printf("%s.%03d (%s) [last sync %s]: %s\n",timeStringBuff, now.tv_usec/1000, buf_now_local.tm_isdst ? "DST" : "STD", lastSyncStringBuff, logicValue ? "1" : "0");

    long uptime = millis()/1000;

    // Reboot once a day at noon to address any wifi hiccoughs.
    // (specifically, reboot any time after 12pm as long as it's been at least 20 hours since the last reboot)
    if( uptime > 20*60*60  && buf_now_local.tm_hour >= 12) {
      appendToLog("Initiating daily reboot");
      flashSuccess();
      delay(1000);
      forceReboot();
    }

    // If no sync in last 4h, set the pixel to red and reboot
    if(uptime > 4*60*60 && now.tv_sec - lastSync.tv_sec > 60 * 60 * 4 ) {
      appendToLog("Last sync more than four hours ago, rebooting.");
      flashFailure();
      delay(3000);
      forceReboot();
    }
  }

  if (logicBits != prevLogicBits) {
    updateCurrentLogicBitsLabel();
  }
}

// Convert a logical bit into a PWM pulse width.
// Returns 50% duty cycle (128) for high, 0% for low
static inline short dutyCycle(bool logicValue) {
  return logicValue ? (256*0.5) : 0; // 128 == 50% duty cycle
}

void createUi() { 
    ControlColor myControlColor = ControlColor::Dark;
    uint16_t mySettingsTab = ESPUI.addControl(ControlType::Tab, "Settings", "Settings");
    uint16_t myLogTab = ESPUI.addControl(ControlType::Tab, "Log", "Log");

    // host name
    ESPUI.addControl(ControlType::Text, "Hostname:", theHostname.c_str(), myControlColor, mySettingsTab, &setHostname);

    // ntp server
    ESPUI.addControl(ControlType::Text, "NTP Server:", theNtpServer.c_str(), myControlColor, mySettingsTab, &setNtpServer);

    // time zone string
    ESPUI.addControl(ControlType::Text, "Time Zone String:", theTimezone.c_str(), myControlColor, mySettingsTab, &setTimezoneFromSelect);

    const char* myServiceString = getStringForService(theService);

    // time service
    uint16_t myServiceSelect
        = ESPUI.addControl(ControlType::Select, "Time Service:", myServiceString, myControlColor, mySettingsTab, &setServiceFromSelect);
    ESPUI.addControl(ControlType::Option, "WWVB (USA)", "WWVB", ControlColor::None, myServiceSelect);
    ESPUI.addControl(ControlType::Option, "DCF77 (EU)", "DCF77", ControlColor::None, myServiceSelect);
    ESPUI.addControl(ControlType::Option, "JJY40 (ASIA)", "JJY40", ControlColor::None, myServiceSelect);
    ESPUI.addControl(ControlType::Option, "JJY60 (ASIA)", "JJY60", ControlColor::None, myServiceSelect);
    ESPUI.addControl(ControlType::Option, "MSF (UK)", "MSF", ControlColor::None, myServiceSelect);
    ESPUI.addControl(ControlType::Option, "Legacy Mode (OG Code)", "LEGACY", ControlColor::None, myServiceSelect);

    // enable flashing
    ESPUI.addControl(ControlType::Switcher, "Enable Flashing", enableFlashing ? "1" : "0", myControlColor, mySettingsTab, &setEnableFlashing);
    
    // write preferences to nvs
    ESPUI.addControl(ControlType::Button, "Persist Settings", "Save", ControlColor::Wetasphalt, mySettingsTab, &handlePersistSettings);

    // reboot
    ESPUI.addControl(ControlType::Button, "Reboot Device", "Reboot", ControlColor::Wetasphalt, mySettingsTab, &handleReboot);

    // logs
    liveLogHandle = ESPUI.addControl(ControlType::Label, "Log Output", "", myControlColor, myLogTab);
    liveLogicBitsHandle = ESPUI.addControl(ControlType::Label, "Current Logic Bits", "", myControlColor, myLogTab);

    ESPUI.beginLITTLEFS("Radio Controlled Watch Tower Administration");
}

void attachPwmPin() {
  int myFrequency = getFrequencyForService(theService);
  appendToLogFormat("using frequency: %d", myFrequency);
  ledcAttach(PIN_ANTENNA, myFrequency, 8);
}

void detachPwmPin() {
    appendToLog("detaching pwm pin");
    digitalWrite(PIN_ANTENNA, 0);
    ledcDetach(PIN_ANTENNA);
}

void updateTimezone() { 
    setenv("TZ",theTimezone.c_str(),1);
    tzset();
}

void appendToLogFormat(const char * format, ...) {
    static char buffer[256]; // A static buffer to store the formatted string
    va_list args;
    va_start(args, format);
    vsnprintf(buffer, sizeof(buffer), format, args); // Use vsnprintf for safety
    va_end(args);
    
    appendToLog(buffer);
}

void readPreferences() { 
    thePreferences.begin("watchtower", true);
    Serial.println("Reading preferences");
    theNtpServer = thePreferences.getString("ntp-Server", "pool.ntp.org");
    theTimezone = thePreferences.getString("timezone", "EST5EDT,M3.2.0,M11.1.0");
    theHostname = thePreferences.getString("hostname", "wwvb");
    const char *myServiceString = thePreferences.getString("timeService", "AAIOT-WWVB").c_str();
    theService = getServiceForString(myServiceString);
    enableFlashing = thePreferences.getBool("enableFlashing", true);

    Serial.printf("Preferences read: {ntp server: %s, timezone: %s, hostname: %s, service: %d, enableFlashing: %d}\n",
        theNtpServer,
        theTimezone.c_str(),
        theHostname,
        theService,
        enableFlashing
        );
    thePreferences.end();
}

void savePreferences() {
    thePreferences.begin("watchtower", false);
    String myService = getStringForService(theService);
    thePreferences.putString("ntp-Server", theNtpServer);
    thePreferences.putString("timezone", theTimezone);
    thePreferences.putString("timeService", myService);
    thePreferences.putString("hostname", theHostname);
    thePreferences.putBool("enableFlashing", enableFlashing);
    thePreferences.end();
}

void updateCurrentLogicBitsLabel() { 
    // convert logicBits to string
    // set string
    String myString = "";
    for (int i = 63; i >= 0; --i) {
        if ((logicBits >> i) & 1) {
            myString += '1';
        } else {
            myString += '0';
        }
    }
    ESPUI.updateText(liveLogicBitsHandle, myString);
}

static inline void flashSuccess() {
    for (int i = 0; i < 3; i++) {
        digitalWrite(PIN_LED, HIGH);
        delay(100);
        digitalWrite(PIN_LED, LOW);
        delay(100);
    }
}

static inline void flashFailure() {
    for (int i = 0; i < 7; i++) {
        digitalWrite(PIN_LED, HIGH);
        delay(500);
        digitalWrite(PIN_LED, LOW);
        delay(500);
    }
    digitalWrite(PIN_LED, HIGH);
}


void setHostname(Control* sender, int type) {
    appendToLogFormat("Updating hostname based on value: %s", sender->value);
    theHostname = sender->value.c_str();
    appendToLogFormat("Updated hostname to: %s", theHostname);
}

void setNtpServer(Control* sender, int type) {
    appendToLogFormat("Updating ntp server based on value: %s", sender->value);
    theNtpServer = sender->value.c_str();
    appendToLogFormat("Updated ntp server to: %s", theNtpServer);
}

void setEnableFlashing(Control* sender, int value) {
    switch (value)
    {
    case S_ACTIVE:
        appendToLog("Enable flashing");
        enableFlashing = true;
        break;

    case S_INACTIVE:
        appendToLog("Disable flashing");
        enableFlashing = false;
        break;
    }
}

void setServiceFromSelect(Control* sender, int value)
{
    appendToLogFormat("Updating service based on value: %s", sender->value);
    theService = getServiceForString(sender->value.c_str());
    detachPwmPin();
    attachPwmPin();
    appendToLogFormat("Updated time service to: %d", theService);
}

void setTimezoneFromSelect(Control* sender, int value)
{
    appendToLogFormat("Updating timezone based on value: %s", sender->value);
    theTimezone = sender->value;
    updateTimezone();
    appendToLogFormat("Updated timezone to: %s", theTimezone);
}

void handlePersistSettings(Control* sender, int type) {
    if (type == B_UP) {
        appendToLog("Persisting settings to NVS");
        savePreferences();
    }
}

void handleReboot(Control* sender, int type) {
    if (type == B_UP) {
        appendToLog("Forced reboot NOW");
        forceReboot();
    }
}

int theLogCounter = 0;
void appendToLog(const String& message) {
    Serial.println(message);
    logBuffer += message + "\n";
    // Optionally, limit the size of logBuffer to prevent memory issues
    if (logBuffer.length() > 512) { // Example limit
        logBuffer = logBuffer.substring(logBuffer.indexOf('\n') + 1);
    }

    if (true || ++theLogCounter % 10 == 0) {
        theLogCounter = 0;
        ESPUI.updateText(liveLogHandle, logBuffer); // Assuming "logLabel" is the ID of your label
    }
}

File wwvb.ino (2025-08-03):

// Derived from https://github.com/anishathalye/micro-wwvb/blob/master/src/microwwvb.c
// https://www.instructables.com/WWVB-radio-time-signal-generator-for-ATTINY45-or-A/
// https://en.wikipedia.org/wiki/WWVB
// https://www.nist.gov/pml/time-and-frequency-division/time-distribution/radio-station-wwvb/wwvb-time-code-format
//
// Simulator: https://wokwi.com/projects/431240334467357697
//      (make sure to comment out the wifi bits)
//      (may also need to change the antenna pin)
//

#include <WiFiManager.h>
#include <Adafruit_NeoPixel.h>
#include "time.h"
#include "esp_sntp.h"

enum WWVB_T {
  ZERO = 0,
  ONE = 1,
  MARK = 2,
};

const int PIN_ANTENNA = 13;
const int KHZ_60 = 60000;

// Set to your timezone.
// This is needed for computing DST if applicable
const char *timezone = "PST8PDT,M3.2.0,M11.1.0"; // America/Los_Angeles
const char* ntpServer = "pool.ntp.org";

WiFiManager wifiManager;
Adafruit_NeoPixel pixels(1, PIN_NEOPIXEL, NEO_GRB + NEO_KHZ800);
bool logicValue = 0; // TODO rename
struct timeval lastSync;

const uint32_t COLOR_READY = pixels.Color(0, 60, 0);
const uint32_t COLOR_LOADING = pixels.Color(32, 20, 0);
const uint32_t COLOR_ERROR = pixels.Color(150, 0, 0);
const uint32_t COLOR_TRANSMIT = pixels.Color(32, 20, 0);

// A tricky way to force arduino to reboot
// by accessing a protected memory address
void(* forceReboot) (void) = 0;

// A callback that tracks when we last sync'ed the
// time with the ntp server
void time_sync_notification_cb(struct timeval *tv) {
  lastSync = *tv;
}

void setup() {
  Serial.begin(115200);
  delay(1000);
  pixels.begin(); // INITIALIZE NeoPixel strip object (REQUIRED)

  pinMode(PIN_ANTENNA, OUTPUT);
  pixels.setPixelColor(0, COLOR_LOADING );
  pixels.show();

  // hack for this on esp32 qt py?
  // E (14621) rmt: rmt_new_tx_channel(269): not able to power down in light sleep
  digitalWrite(PIN_ANTENNA, 0);

  // https://github.com/tzapu/WiFiManager/issues/1426
  WiFi.setScanMethod(WIFI_ALL_CHANNEL_SCAN);

  // Connect to WiFi using // https://github.com/tzapu/WiFiManager 
  // If no wifi, start up an SSID called "WWVB" so
  // the user can configure wifi using their phone.
  wifiManager.autoConnect("WWVB");

  // Connect to network time server
  // By default, it will resync every hour
  // Register a callback to be informed when we sync
  sntp_set_time_sync_notification_cb(time_sync_notification_cb);
  configTime(0, 0, ntpServer);
  struct tm timeinfo;
  if(!getLocalTime(&timeinfo)){
    Serial.println("Failed to obtain time");
    pixels.setPixelColor(0, COLOR_ERROR );
    pixels.show();
    delay(3000);
    forceReboot();
  }
  Serial.println("Got the time from NTP");

  // Now we can set the real timezone.
  // We broadcast in UTC, but we need the timezone for the is_dst bit
  setenv("TZ",timezone,1);  //  Now adjust the TZ.  Clock settings are adjusted to show the new local time
  tzset();

  // Start the 60khz carrier signal using 8-bit (0-255) resolution
  ledcAttach(PIN_ANTENNA, KHZ_60, 8);

  // green means go
  pixels.setPixelColor(0, COLOR_READY );
  pixels.show();
  delay(3000);

  pixels.clear();  
  pixels.show();
}

void loop() {
  // TODO add sleep for planet earth

  // now and buf_now are used for the current time.
  struct timeval now, today_start, tomorrow_start;
  struct tm buf_now_utc, buf_now_local, buf_today_start, buf_tomorrow_start;
  gettimeofday(&now,NULL);
  gmtime_r(&now.tv_sec, &buf_now_utc); 
  localtime_r(&now.tv_sec, &buf_now_local);

  today_start = now;
  today_start.tv_usec = 0;
  today_start.tv_sec = (today_start.tv_sec / 86400) * 86400; // This is not exact but close enough
  localtime_r(&today_start.tv_sec, &buf_today_start);

  tomorrow_start = now;
  tomorrow_start.tv_usec = 0;
  tomorrow_start.tv_sec = ((tomorrow_start.tv_sec / 86400) + 1) * 86400; // again, close enough
  localtime_r(&tomorrow_start.tv_sec, &buf_tomorrow_start);


  // DEBUGGING
  // If you're not sure if your clock is being set,
  // you can uncomment these lines to offset the
  // time by 30 minutes
  // buf_now_utc.tm_min = buf_now_local.tm_min = (buf_now_utc.tm_min + 30) % 60;
  // or set the date to dec 31
  // buf_now_utc.tm_yday = buf_now_local.tm_yday = 365;
  // or set the time randomly ever 10 minutes
  // int mod_min = buf_now_utc.tm_min % 10;
  // randomSeed(buf_now_utc.tm_min / 10); // pick a new random time every 10m
  // buf_now_utc.tm_hour = buf_now_local.tm_hour = random(0,24);
  // buf_now_utc.tm_min = buf_now_local.tm_min = (random(0,60) + mod_min) % 60;


  const bool prevLogicValue = logicValue;

  logicValue = wwvbLogicSignal(
    buf_now_utc.tm_hour,
    buf_now_utc.tm_min,
    buf_now_utc.tm_sec, 
    now.tv_usec/1000,
    buf_now_utc.tm_yday+1,
    buf_now_utc.tm_year+1900,
    buf_today_start.tm_isdst,
    buf_tomorrow_start.tm_isdst
    );

  if( logicValue != prevLogicValue ) {
    ledcWrite(PIN_ANTENNA, dutyCycle(logicValue));  // Update the duty cycle of the PWM

    // light up the pixel if desired
    // if( logicValue == 1 ) {
    //   pixels.setPixelColor(0, COLOR_TRANSMIT ); // don't call show yet, the color may change
    // } else {
    //   pixels.clear();
    // }

    // do any logging after we set the bit to not slow anything down,
    // serial port I/O is slow!
    char timeStringBuff[100]; // Buffer to hold the formatted time string
    strftime(timeStringBuff, sizeof(timeStringBuff), "%A, %B %d %Y %H:%M:%S", &buf_now_local);

    char lastSyncStringBuff[100]; // Buffer to hold the formatted time string
    struct tm buf_lastSync;
    localtime_r(&lastSync.tv_sec, &buf_lastSync);
    strftime(lastSyncStringBuff, sizeof(lastSyncStringBuff), "%b %d %Y %H:%M", &buf_lastSync);
    Serial.printf("%s.%03d (%s) [last sync %s]: %s\n",timeStringBuff, now.tv_usec/1000, buf_now_local.tm_isdst ? "DST" : "STD", lastSyncStringBuff, logicValue ? "1" : "0");

    // If no sync, set the pixel to red
    if( now.tv_sec - lastSync.tv_sec > 60 * 60 * 4 ) {
      pixels.setPixelColor(0, COLOR_ERROR );
    }

    pixels.show();  
  }  
}

// Convert a logical bit into a PWM pulse width.
// Returns 50% duty cycle (128) for high, 0% for low
static inline short dutyCycle(bool logicValue) {
  return logicValue ? (256*0.5) : 0; // 128 == 50% duty cycle
}
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

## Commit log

2025-05-18 add led indicator
    also remove serial port which might be slowing down the loop
2025-05-18 switch pin, try gmt to help debugging
2025-07-18 fix off by one ms error
    [wwvb.ino]
2025-07-18 fix the year value
    [wwvb.ino]
2025-07-24 Revert "365>364 untested"
    This reverts commit fa106eb8ee194162acfc4a7ef8fb471a490d6f90.
    [wwvb.ino]
2025-07-28 Update wwvb.ino
    change to pin 32 to make wiring cleaner
2025-07-28 Update wwvb.ino
    revert back to gmt
    [wwvb.ino]
2025-07-28 Update wwvb.ino
    switch to qt py pin
    and remove timezone code
2025-07-28 Update wwvb.ino
    fix off by one in yday
    [wwvb.ino]
2025-07-28 Update wwvb.ino
    fix for dst bit
    [wwvb.ino]
2025-07-29 Update wwvb.ino
    force reboot if no ntp
    [wwvb.ino]
2025-07-29 Revert "Update wwvb.ino"
    This reverts commit 9bd285b9e290a9965fe11bfdf39e0c8068d17bd6.
    [wwvb.ino]
2025-07-29 Update wwvb.ino
    turn on LED during boot
    and try hack for rmt_new_tx_channel intermittent issue
    [wwvb.ino]
2025-07-29 Update wwvb.ino
    light up the LED if there hasn't been a time sync in 4h
2025-07-30 Update wwvb.ino
    switch to color pixel indicators
2025-08-02 Update wwvb.ino
    try a fix for getting disconnected from nest wifi
    [wwvb.ino]
2025-08-03 switch to animated photo
2025-08-03 word -> frame
2025-08-03 Add stl and f3d file
    [The Watch Tower v7.f3d, The Watch Tower v7.stl]
2025-08-03 don't put frame in quotes
2025-08-05 Update WatchTower.ino
    Add a daily reboot at 5pm
    [WatchTower.ino]
2025-08-06 don't reboot constantly after 5pm
    [WatchTower.ino]
2025-08-09 Update WatchTower.ino
    cleaner way to reboot once a day
    [WatchTower.ino]
2025-08-09 reboot if no sync in 4h
    [WatchTower.ino]
2025-08-09 update stls to v15
    [The Watch Tower v15.f3d, The Watch Tower v15.stl, The Watch Tower v7.f3d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]
2025-08-10 Update WatchTower.ino
    remove todo.
    we can't sleep, or if we do the savings will be minimal because the majority of the power is going to the antenna
2025-08-10 Update WatchTower.ino
    fix dec 31 debugging date
    [WatchTower.ino]
2025-08-10 fix the way i change the date for debugging
    change the date earlier so all the subsequent date objects are consistent
    [WatchTower.ino]
2025-08-10 dim led
2025-08-10 update I2c for qt py
2025-08-10 update docs to show second-antenna board layout
2025-08-11 notes about two antennae
2025-08-11 set the debugging date to the 1st
    avoids DST issues and remove the need for the reboot hack
    also dim the LED
    [WatchTower.ino]
2025-08-16 v18 STL. Gets rid of antenna support components in v15. Reduces height. Antenna is now expected to rest on protoboard between microcontroller and amplifier.
    [The Watch Tower v15.f3d, The Watch Tower v15.stl, The Watch Tower v18.f3d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]
2025-08-30 updates about second antenna
2025-09-13 Add support for Web GUI and Multiple RC Protocols
    Add support for multiple time formats by extending the work of
    the time_signal project to wrap that output into a boolean val
    used to drive the signal high / low. Keep the option of running
    the old, legacy code by adding a new enum value LEGACY
    Add support for configuring hostname, NTP Server, timezone, time
    service and LED flash behavior dynamically at run time by adding
    a web gui using ESPUI.
    These parameters can be set either until reset or persisted in
    NVS by hitting the Save button.
    Additionally, expose a reboot button and useful log information
    in a separate tab.
    [zones.csv]
2025-09-13 Add new STL file
    Add a new enclosure STL which has been split into two pieces which
    fit together at assembly, making it easier to place the internal
    components.
    Add a picture of this new build to the README
    [The Watch Tower v18.f3d, The Watch Tower v18.stl, WWVB Radio Watch Tower.stl]
